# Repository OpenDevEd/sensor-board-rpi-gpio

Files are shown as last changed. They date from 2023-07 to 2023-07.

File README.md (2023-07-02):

# sensor-board-rpi-gpio

This is a breakout board for the Raspberry Pi GPIO. The purpose of the board is to testing several sensor sensor breakouts available in the UK, including the following:
* AHT20 (Adafruit)
* BH1750 (DFRobot/Femion)
* ENS160 (DFRobot/Femion)
* I2S MEMS Mic (Adafruit)
* I2S MEMS Mic (DFRobot/Femion)
* LTR-559 (Pimoroni)
* MCP9808 (Adafruit)
* SHT31 (Adafruit)
* SHT40/45 (Adafruit)
* SCD40/41 (Adafruit, Pimoroni, ebay)

Certain GPIO are not utilised by the board, because the board is meant to function with the Adafruit LoRa Bonnet (and PiJuice Zero).

Motivation: https://opendeved.net/ilce

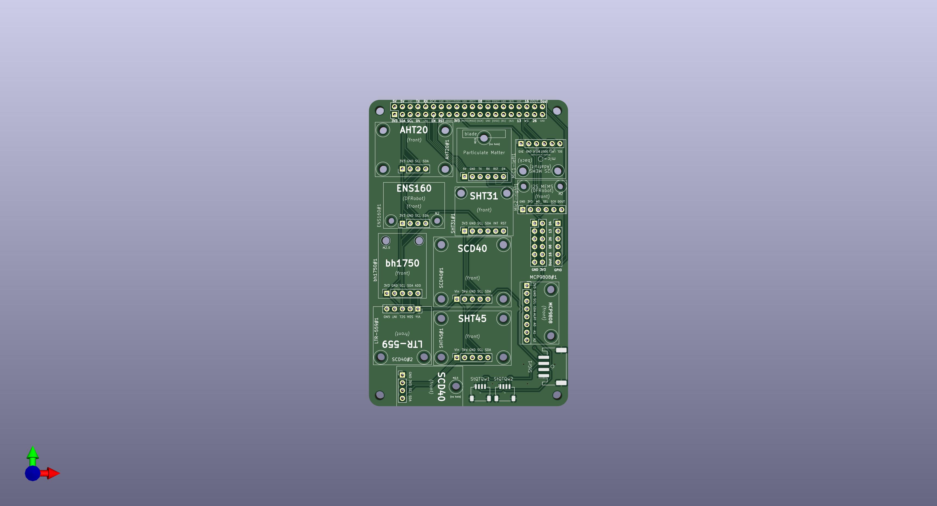
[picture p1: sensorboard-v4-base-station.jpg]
sensorboard-v4-base-station

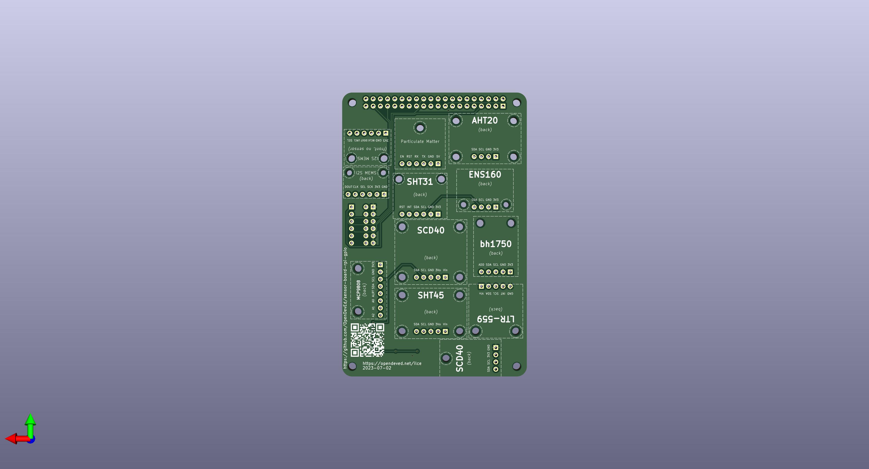
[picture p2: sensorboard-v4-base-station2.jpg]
sensorboard-v4-base-station2


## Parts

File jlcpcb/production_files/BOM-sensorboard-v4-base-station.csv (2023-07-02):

Comment | Designator | Footprint | LCSC
StemmaQT-Qwiic (horizontal) | StQTQw1,StQTQw2 | StemmaQT-Qwiic (horizontal) | C145956
Stemma-Grove (full size, horizontal) | StGr1 | Stemma-Grove (full size, horizontal) | C519170

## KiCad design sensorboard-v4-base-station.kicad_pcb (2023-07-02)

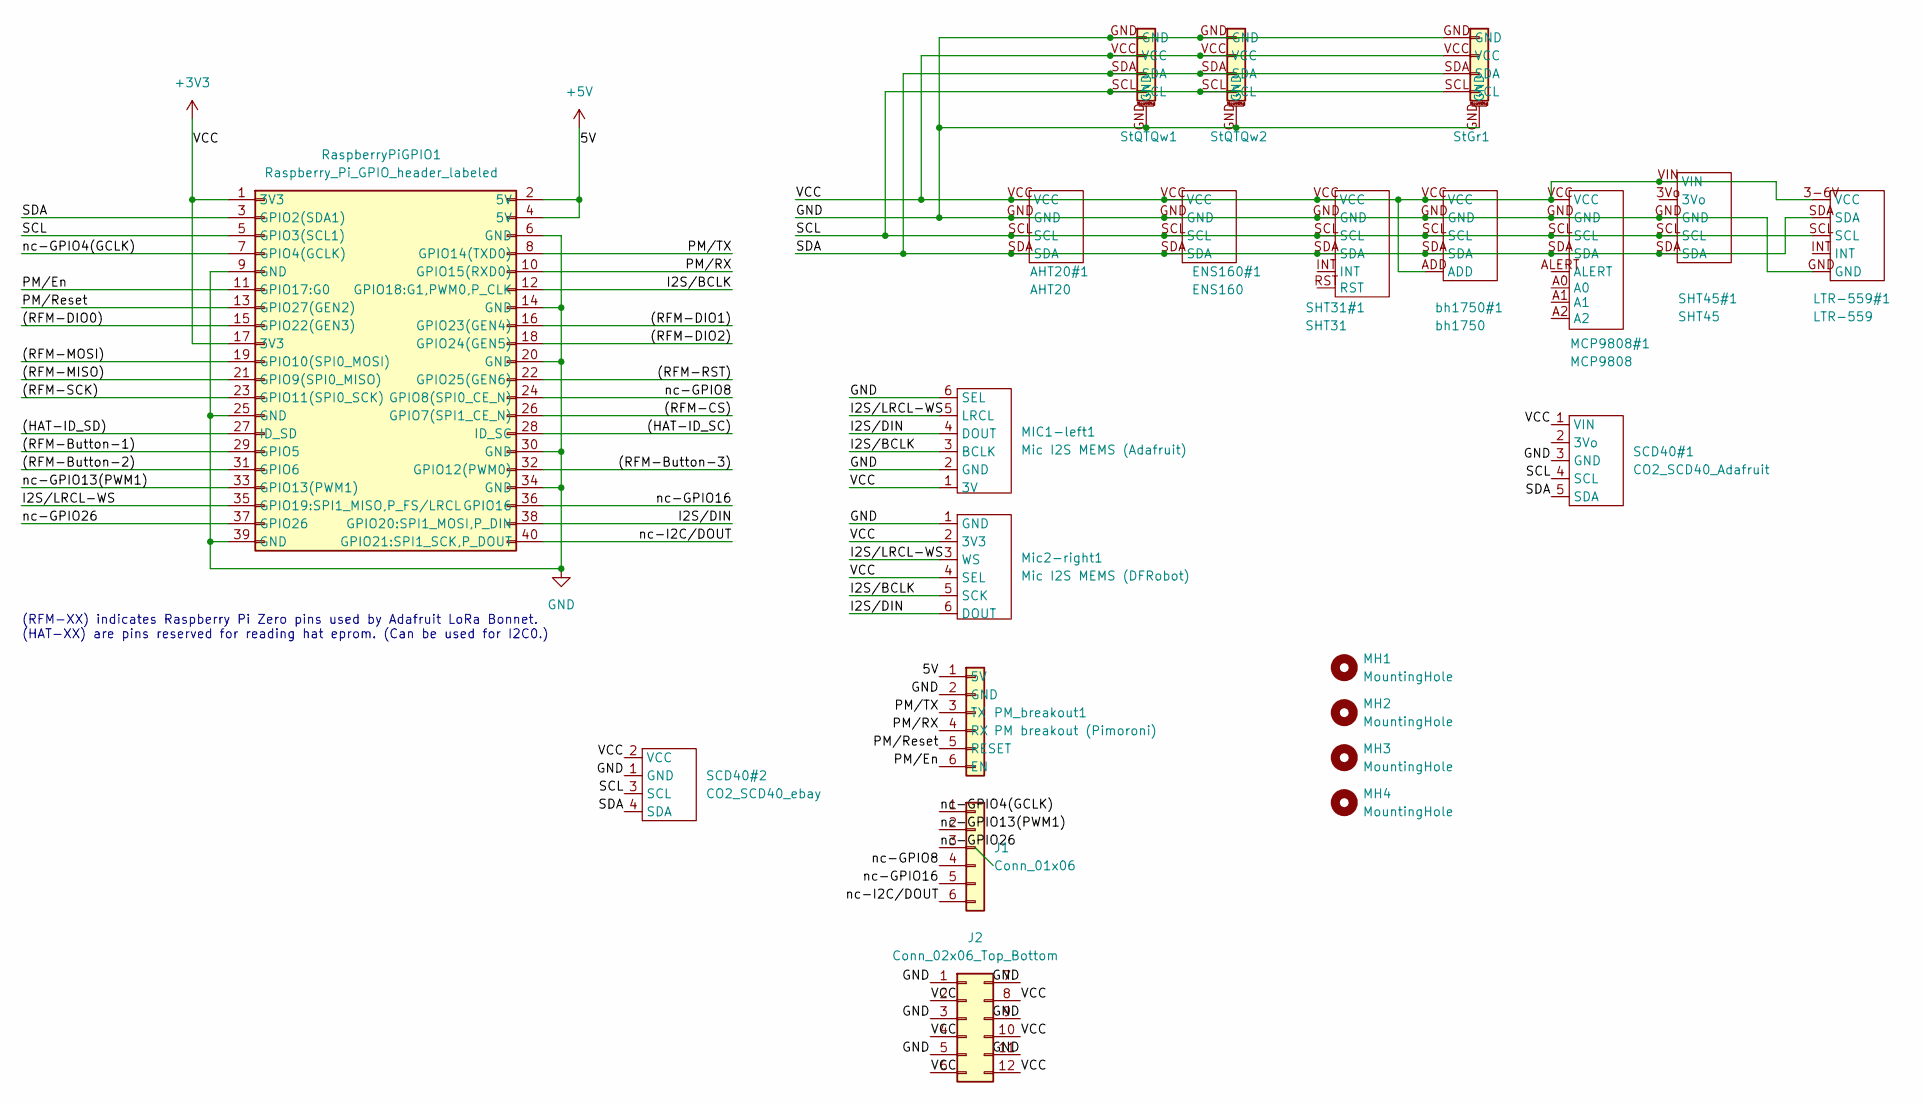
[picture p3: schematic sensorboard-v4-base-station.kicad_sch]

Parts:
AHT20#1: AHT20; AHT20 (Adafruit)
ENS160#1: ENS160; ENS160 (DFROBOT, Fermion), i2c pads
J1: Conn_01x06; PinHeader_1x06_P2.54mm_Vertical
J2: Conn_02x06_Top_Bottom; PinHeader_2x06_P2.54mm_Vertical; LCSC C6332209
LTR-559#1: LTR-559; LTR-559 (Pimoroni)
MCP9808#1: MCP9808; MCP9808 (Adafruit, original version)
MH1, MH2, MH3, MH4: MountingHole
MIC1-left1: Mic I2S MEMS (Adafruit)
Mic2-right1: Mic I2S MEMS (DFRobot)
PM_breakout1: PM breakout (Pimoroni); Particulate Matter Sensor Breakout (for PMS5003)
RaspberryPiGPIO1: Raspberry_Pi_GPIO_header_labeled; PinHeader_2x20_P2.54mm_Vertical; LCSC C5224014
SCD40#1: CO2_SCD40_Adafruit; SCD40 CO2 (Adafruit)
SCD40#2: CO2_SCD40_ebay; SCD40 CO2 (ebay)
SHT31#1: SHT31; SHT31 (DFR, Fermion)
SHT45#1: SHT45; SHT45 (Adafruit)
StGr1: Stemma-Grove (full size, horizontal); LCSC C519170
StQTQw1, StQTQw2: StemmaQT-Qwiic (horizontal); LCSC C145956
bh1750#1: bh1750; bh1750 (DFROBOT, Fermion)

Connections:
+3V3: AHT20#1.VCC, ENS160#1.VCC, J2.2, J2.4, J2.6, J2.8, J2.10, J2.12, LTR-559#1.3-6V (VCC), MCP9808#1.VCC, MIC1-left1.1 (3V), Mic2-right1.2 (3V3), Mic2-right1.4 (SEL), RaspberryPiGPIO1.1 (3V3), RaspberryPiGPIO1.17 (3V3), SCD40#1.1 (VIN), SCD40#2.2 (VCC), SHT31#1.VCC, SHT45#1.VIN, StGr1.VCC, StQTQw1.VCC, StQTQw2.VCC, bh1750#1.ADD, bh1750#1.VCC
+5V: PM_breakout1.1 (5V), RaspberryPiGPIO1.2 (5V), RaspberryPiGPIO1.4 (5V)
/(HAT-ID_SC): RaspberryPiGPIO1.28 (ID_SC)
/(HAT-ID_SD): RaspberryPiGPIO1.27 (ID_SD)
/(RFM-Button-1): RaspberryPiGPIO1.29 (GPIO5)
/(RFM-Button-2): RaspberryPiGPIO1.31 (GPIO6)
/(RFM-Button-3): RaspberryPiGPIO1.32 (GPIO12(PWM0))
/(RFM-CS): RaspberryPiGPIO1.26 (GPIO7(SPI1_CE_N))
/(RFM-DIO0): RaspberryPiGPIO1.15 (GPIO22(GEN3))
/(RFM-DIO1): RaspberryPiGPIO1.16 (GPIO23(GEN4))
/(RFM-DIO2): RaspberryPiGPIO1.18 (GPIO24(GEN5))
/(RFM-MISO): RaspberryPiGPIO1.21 (GPIO9(SPI0_MISO))
/(RFM-MOSI): RaspberryPiGPIO1.19 (GPIO10(SPI0_MOSI))
/(RFM-RST): RaspberryPiGPIO1.22 (GPIO25(GEN6))
/(RFM-SCK): RaspberryPiGPIO1.23 (GPIO11(SPI0_SCK))
/I2S/BCLK: MIC1-left1.3 (BCLK), Mic2-right1.5 (SCK), RaspberryPiGPIO1.12 (GPIO18:G1,PWM0,P_CLK)
/I2S/DIN: MIC1-left1.4 (DOUT), Mic2-right1.6 (DOUT), RaspberryPiGPIO1.38 (GPIO20:SPI1_MOSI,P_DIN)
/I2S/LRCL-WS: MIC1-left1.5 (LRCL), Mic2-right1.3 (WS), RaspberryPiGPIO1.35 (GPIO19:SPI1_MISO,P_FS/LRCL)
/PM/En: PM_breakout1.6 (EN), RaspberryPiGPIO1.11 (GPIO17:G0)
/PM/RX: PM_breakout1.4 (RX), RaspberryPiGPIO1.10 (GPIO15(RXD0))
/PM/Reset: PM_breakout1.5 (RESET), RaspberryPiGPIO1.13 (GPIO27(GEN2))
/PM/TX: PM_breakout1.3 (TX), RaspberryPiGPIO1.8 (GPIO14(TXD0))
/SCL: AHT20#1.SCL, ENS160#1.SCL, LTR-559#1.SCL, MCP9808#1.SCL, RaspberryPiGPIO1.5 (GPIO3(SCL1)), SCD40#1.4 (SCL), SCD40#2.3 (SCL), SHT31#1.SCL, SHT45#1.SCL, StGr1.SCL, StQTQw1.SCL, StQTQw2.SCL, bh1750#1.SCL
/SDA: AHT20#1.SDA, ENS160#1.SDA, LTR-559#1.SDA, MCP9808#1.SDA, RaspberryPiGPIO1.3 (GPIO2(SDA1)), SCD40#1.5 (SDA), SCD40#2.4 (SDA), SHT31#1.SDA, SHT45#1.SDA, StGr1.SDA, StQTQw1.SDA, StQTQw2.SDA, bh1750#1.SDA
/nc-GPIO4(GCLK): J1.1, RaspberryPiGPIO1.7 (GPIO4(GCLK))
/nc-GPIO8: J1.4, RaspberryPiGPIO1.24 (GPIO8(SPI0_CE_N))
/nc-GPIO13(PWM1): J1.2, RaspberryPiGPIO1.33 (GPIO13(PWM1))
/nc-GPIO16: J1.5, RaspberryPiGPIO1.36 (GPIO16)
/nc-GPIO26: J1.3, RaspberryPiGPIO1.37 (GPIO26)
/nc-I2C/DOUT: J1.6, RaspberryPiGPIO1.40 (GPIO21:SPI1_SCK,P_DOUT)
GND: AHT20#1.GND, ENS160#1.GND, J2.1, J2.3, J2.5, J2.7, J2.9, J2.11, LTR-559#1.GND, MCP9808#1.GND, MIC1-left1.2 (GND), MIC1-left1.6 (SEL), Mic2-right1.1 (GND), PM_breakout1.2 (GND), RaspberryPiGPIO1.6 (GND), RaspberryPiGPIO1.9 (GND), RaspberryPiGPIO1.14 (GND), RaspberryPiGPIO1.20 (GND), RaspberryPiGPIO1.25 (GND), RaspberryPiGPIO1.30 (GND), RaspberryPiGPIO1.34 (GND), RaspberryPiGPIO1.39 (GND), SCD40#1.3 (GND), SCD40#2.1 (GND), SHT31#1.GND, SHT45#1.GND, StGr1.GND, StQTQw1.GND, StQTQw2.GND, bh1750#1.GND

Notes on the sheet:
(RFM-XX) indicates Raspberry Pi Zero pins used by Adafruit LoRa Bonnet. (HAT-XX) are pins reserved for reading hat eprom. (Can be used for I2C0.)

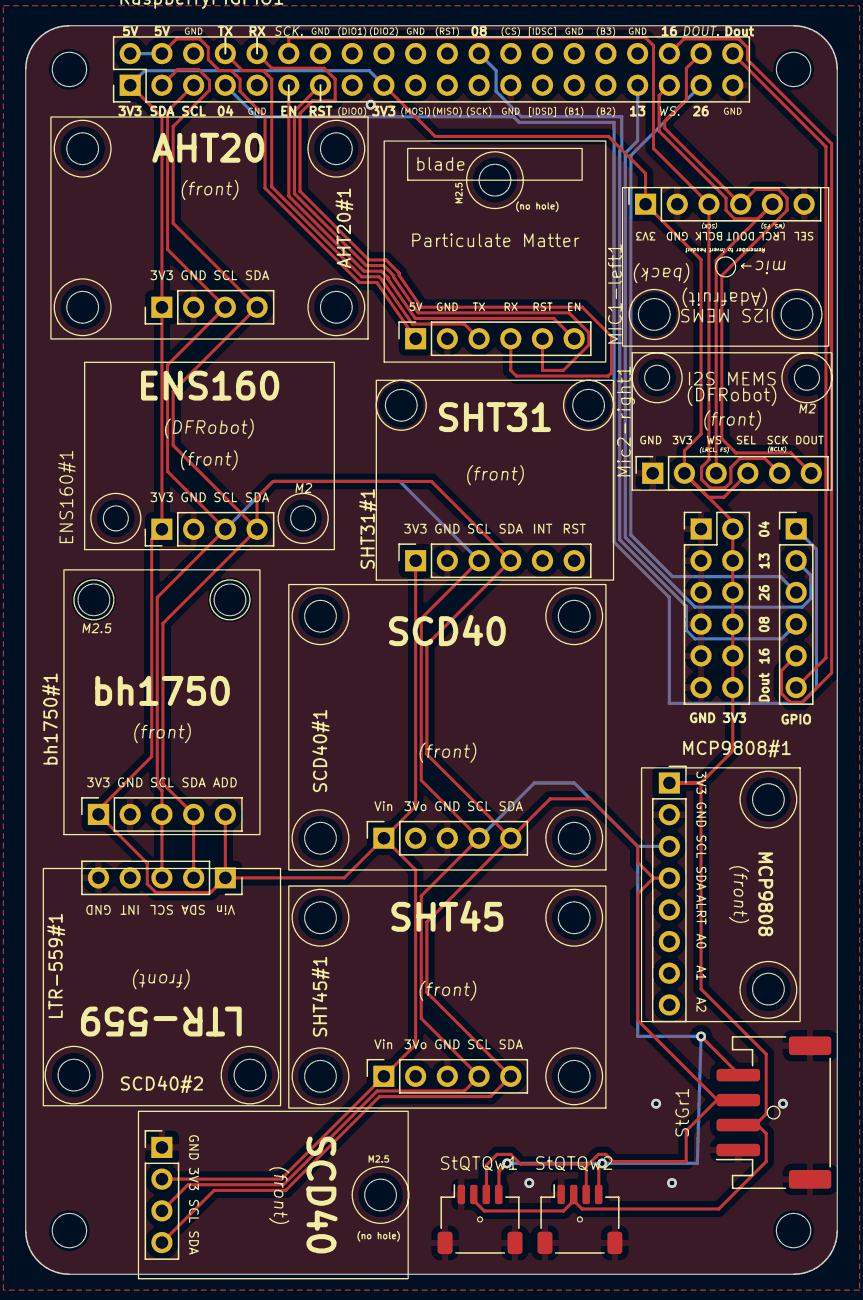
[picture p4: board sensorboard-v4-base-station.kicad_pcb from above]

Board: 2 copper layers, 65.0 x 100.0 mm, 22 parts (0 on the bottom side), 18 nets.
